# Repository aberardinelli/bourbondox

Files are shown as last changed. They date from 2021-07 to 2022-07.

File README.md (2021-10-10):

# bourbondox

`pcb/rev1` folder contains the KiCAD pcb files for v0.1 (received 2021-07-02)

`pcb/rev2` folder contains the KiCAD pcb files for v0.2 (received 2021-07-06)

`pcb/rev3` folder contains the KiCAD pcb files for v0.3 (received 2021-07-19)

`pcb/rev4` folder contains the KiCAD pcb files for v0.4 (received 2021-07-29)

`pcb/rev5` folder contains the KiCAD pcb files for v1.0 (received 2021-08-13)

`firmware` folder contains the qmk firmware files

`case/v1` folder contains the FreeCAD and dxf files for a stacked acrylic case that aligns with the v1.0 pcb (finished 2021-09-10)

There is also a json file (`keyboard-layout_rev1.0.json`) which could be used on keyboard-layout-editor.com

## Changelog and documentation of issues

### v0.1

* Only had one side printed. Diodes were mistakenly put on the front of the PCB in my schematic when they should be on the back.
* Soldered on reset button, promicro controller, and diodes.
* Tested each switch with tweezers. 
* All switches in columns 0, 1, 2, 3, and 4 worked as expected.
* All switches in columns 5 and 6 failed to register. Reset button failed to work.

### v0.2

* Had both sides printed this time. Completely redid the routing from scratch because I wasn't happy with the first version. Did all this and ordered the v0.2 prototypes before I had even received and tested v0.1.
* Soldered reset buttons, TRRS jacks, OLED screens, promicro controllers, diodes, and switches on both halves. Soldered resistors on right side only.
* Reset buttons still didn't work.  But... On each side, when plugged in alone (not connected to other half): All switches worked as expected. Both OLED screens worked as expected.
* When the sides are connected via TRRS cable, switches and OLED screens stopped working. This led me to believe there was a problem with the routing with the TRRS jacks. I ruled out a problem with the cable since I tried two different TRRS cables, both of which worked fine with two other split keyboards.
* Stagger on left hand felt extremely comfortable but right hand was unnatural.

### v0.3

* Changed the footprints on the PCB for the TRRS jacks and reset switches. Rerouted those components on the schematic.
* Reduced the stagger by a small bit on the left side. Reduced the stagger by a lot on the right side.
* Reset buttons work now, on both halves. 
* When it comes to testing the TRRS connection, there are multiple outcomes depending on configuration:
    * If right half has Elite-C and it is connected via USB-C cable to the computer, no switches register and OLEDs are blank.
    * If left half has ProMicro and it is connected via micro USB cable to the computer, no switches register, but the OLEDs each show the same garbled output (first few letters are clear and correct but the rest is nonsense).
    * If NOT connected via TRRS, but each half is connected via its respective USB cable directly to the computer, then OLED screens work as expected and all switches register as expected with tweezers.
* Stagger on left hand seems perfect; right hand might still need adjustments on pinky but seems perfect now for middle and ring fingers. 

### v0.4

* Changed the split communication to serial to allow OLED screens to use i2c. This required changing the routing and footprints in the schematics for the TRRS jacks.
* Very minor adjustments made to spacing of holes for OLED covers.
* Thumb cluster on right side was not great for my use case; rotated the keys on that side. 
* Increased the spacebar size on left side to 2u for more likely compatibility with keycap kits.

## v1.0 photos

*Initial build of v1.0 with cheap tenting provided by acrylic photo frames*
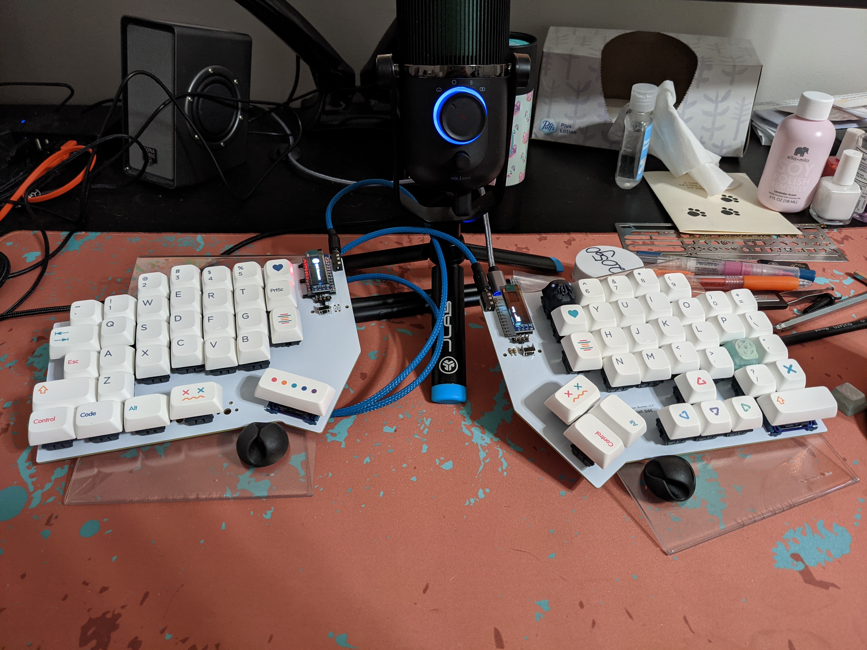
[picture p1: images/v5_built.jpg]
Initial v1.0 build


*v1.0 with better tenting provided by magnetic cell phone holders*
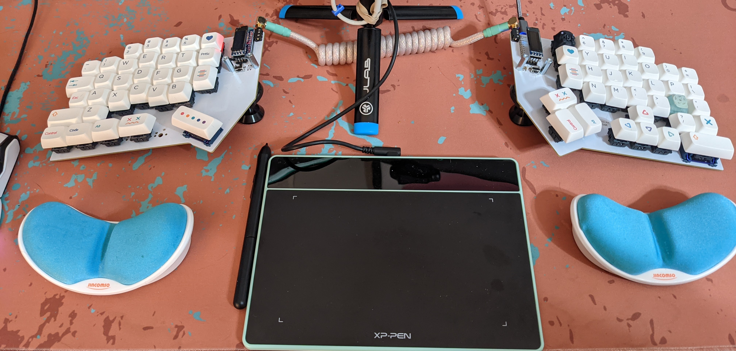
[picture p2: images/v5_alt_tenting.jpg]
v1.0 build with better tenting


## v0.4 photo

*First fully functional build!*
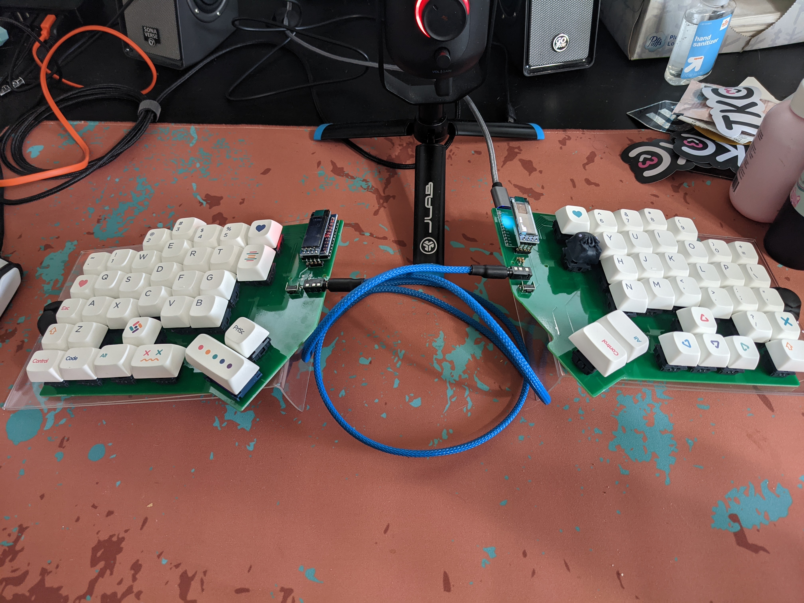
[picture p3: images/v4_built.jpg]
Initial v0.4 build


## v0.3 photos

*Not plugged in*
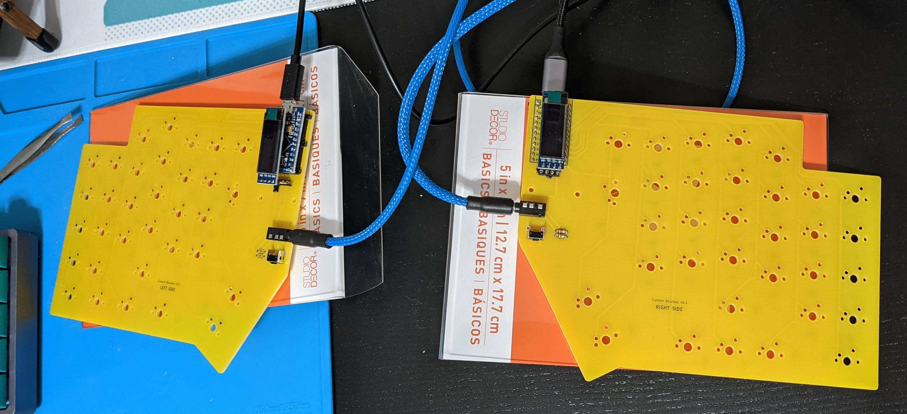
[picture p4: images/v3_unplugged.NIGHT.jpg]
Not plugged in


*Halves are NOT connected, each half is connected to computer via its own cable. OLEDs, switches, and reset buttons work as expected*
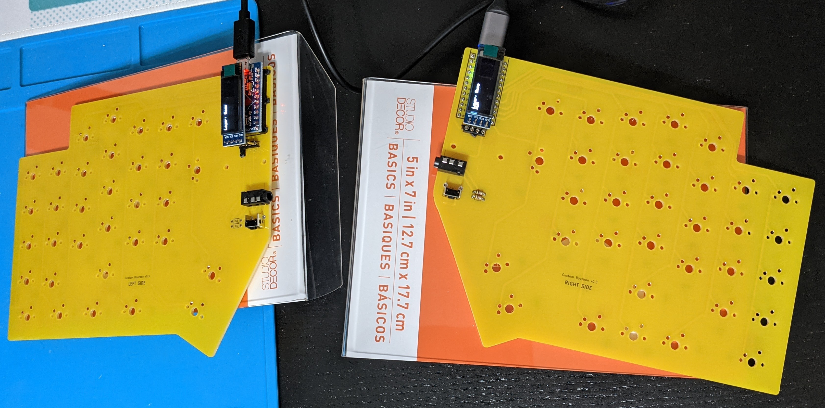
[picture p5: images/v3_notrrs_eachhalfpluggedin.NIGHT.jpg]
Right side plugged in via USB-C


*TRRS connecting the halves, connected to computer via USB-C cable plugged into Elite-C controller on right half of keyboard (controller power buttons light up, but no OLEDs and no switches register)*
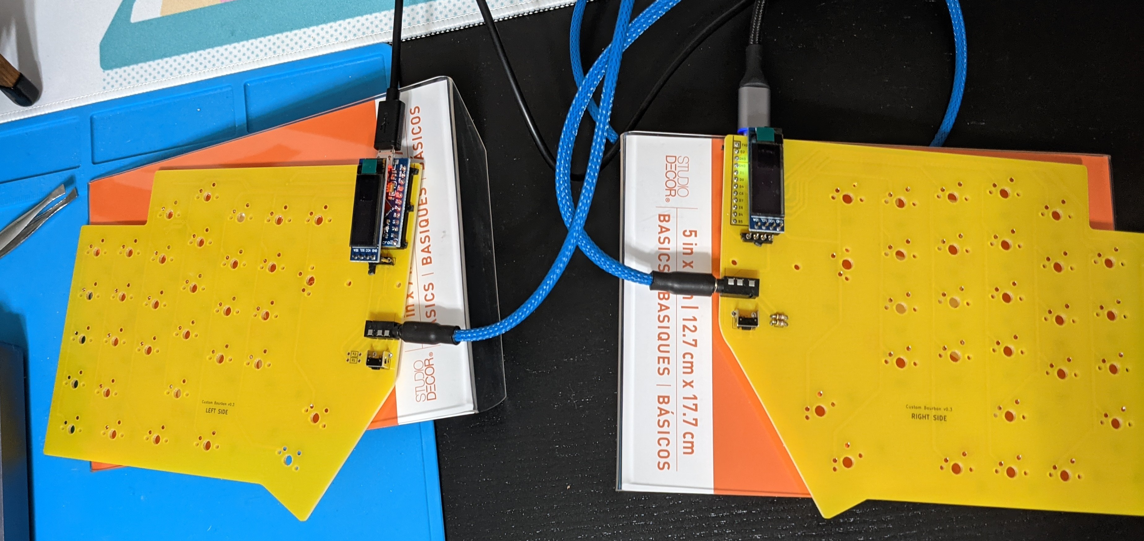
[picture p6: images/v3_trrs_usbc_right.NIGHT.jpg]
Right side plugged in via USB-C


*TRRS connecting the halves, connected to computer via micro USB cable plugged into ProMicro controller on left half of keyboard (controller power buttons light up, but no switches register; OLEDs light up but output is garbled)*
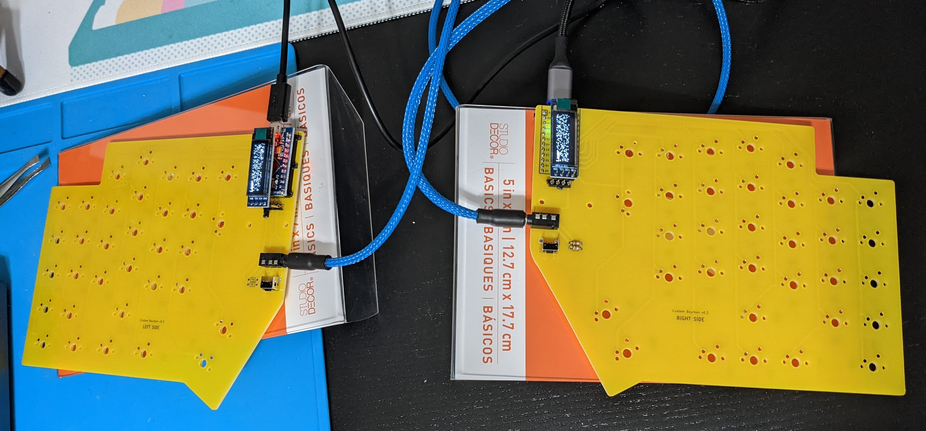
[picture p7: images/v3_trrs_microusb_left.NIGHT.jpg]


## v0.2 photo

*Everything's soldered, but it's not plugged in*
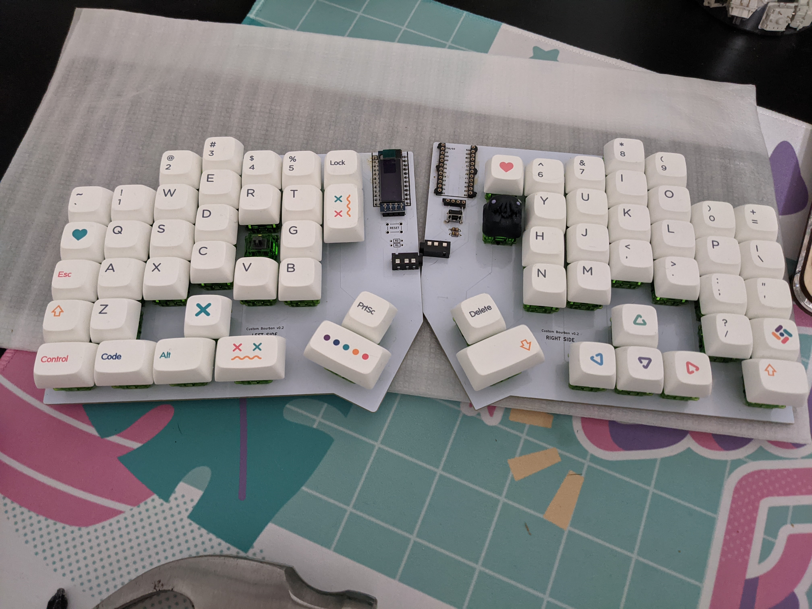
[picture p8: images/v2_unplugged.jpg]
Not plugged in


## v0.1 photos

*No soldering done yet, just placing switches and keycaps to verify fit.*
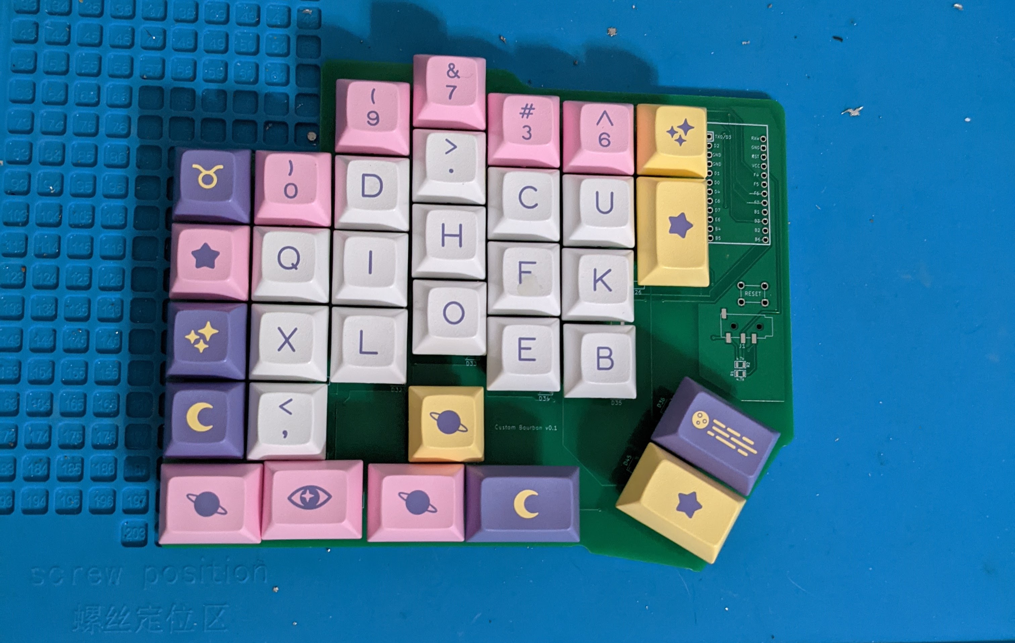
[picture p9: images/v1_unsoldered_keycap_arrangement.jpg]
No soldering done yet


*Soldered diodes, promicro, and reset button to the front. Yes, I know the diodes are supposed to be on the back of the PCB. This is fixed for v0.2.*
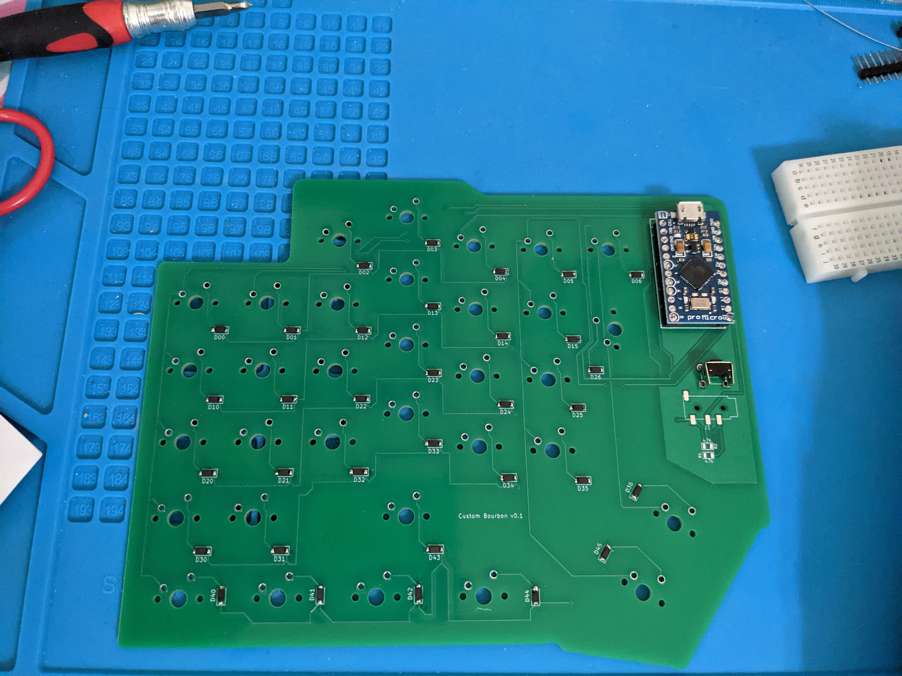
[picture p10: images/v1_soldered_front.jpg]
soldered components on front


*View of the soldering for the promicro on the back of the PCB.*
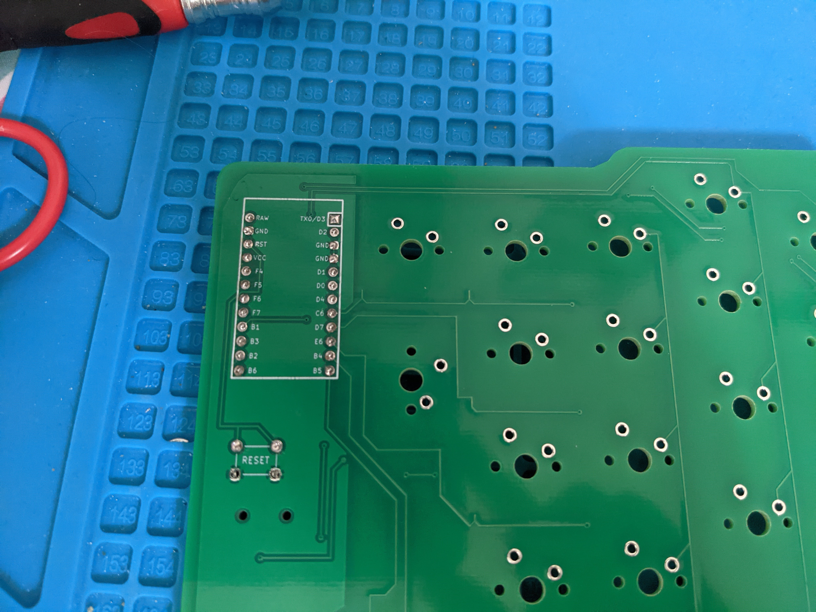
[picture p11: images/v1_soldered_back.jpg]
soldered components on back


*Promicro is flashed and soldered. Ready for testing!*
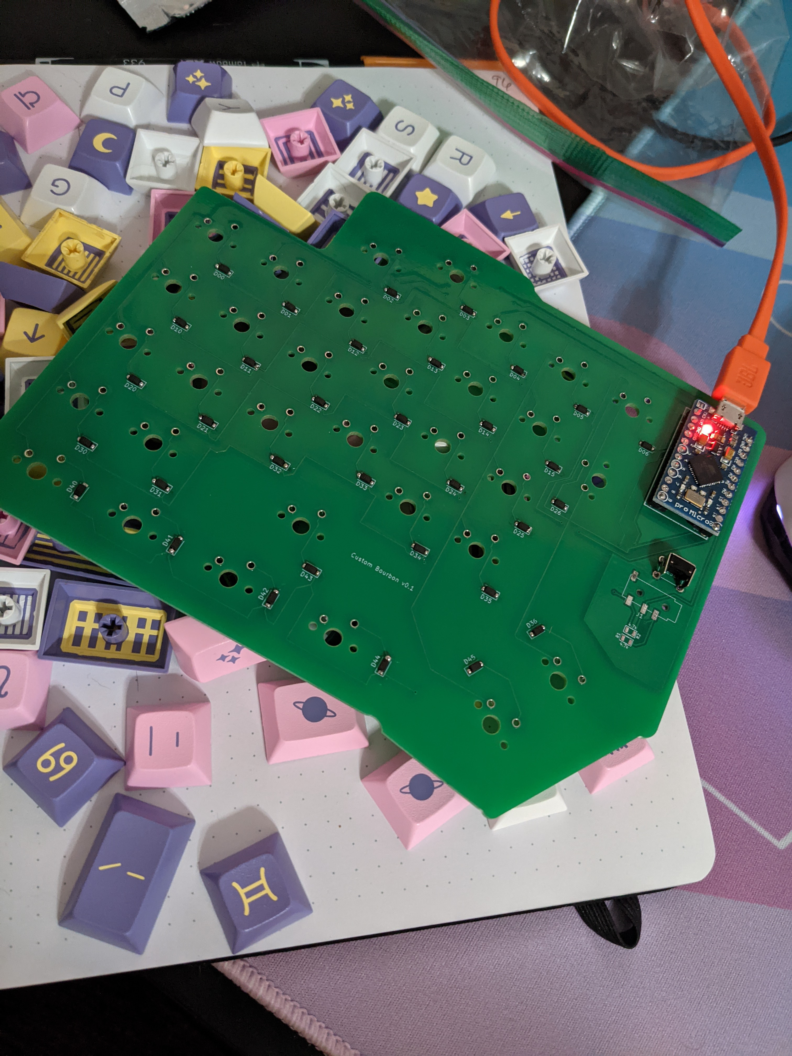
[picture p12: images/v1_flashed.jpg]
Ready for testing


# Acknowledgements

Thank you to ai03 and masterzen for your extensive keyboard pcb design tutorials posted online as resources for the community.

Thank you to the designers of the redox, lily58, and corne-cherry for sharing your work as open source. These were inspirational and helpful resources during my design of this keyboard.

Special thanks to the Keycraft Collective discord community, especially users astra and matthewdias, for their encouragement, feedback, input, and troubleshooting.

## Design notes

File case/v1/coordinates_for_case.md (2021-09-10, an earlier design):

# Left PCB

## Top to bottom measurements

Top layer: 9mm, needs holes for tadpoles 

Plate is ~1.5mm

Middle layers, in line with plate: 9.6mm gives 3mm clearance under pcb 

Acrylic comes in 1/4 inch thickness (>6.3mm)

## Outside points, from top left, clockwise, for all layers

* -76.70 49.70 arc up
* -68.78 55.47 horizontal
* -33.79 55.47 arc up 
* -27.48 61.03 vertical
* -27.48 76.01 arc up 
* -25.93 77.70 horizontal 
* 122.26 77.70 arc down
* 125.67 74.43 vertical
* 125.67 3.61 arc down 
* 123.49 -8.78 60deg from horizontal
* 88.61 -69.19 arc down 
* 80.20 -72.37 30deg from horizontal 
* 59.21 -60.25 arc up 
* 54.41 -58.95 horizontal 
* -68.66 -58.95 arc up 
* -76.7 -51.96 vertical 

## PCB inside points, from top left, clockwise 

Note: 8mm between pcb and outer edge of case

* -68.70 47.47
* -19.48 47.47
* -19.48 69.70
* 113.17 69.70
* 113.17 -10.65
* 82.21 -64.29
* 59.10 -50.95
* -68.70 -50.95

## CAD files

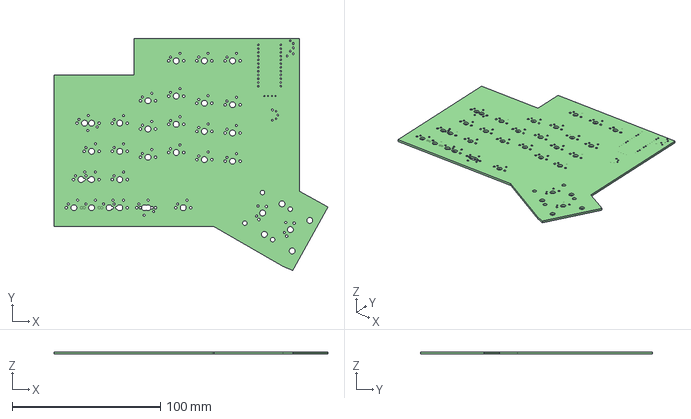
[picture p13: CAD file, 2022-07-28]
case/v3/left_case.FCStd
185.1 x 156.7 x 1.60 mm

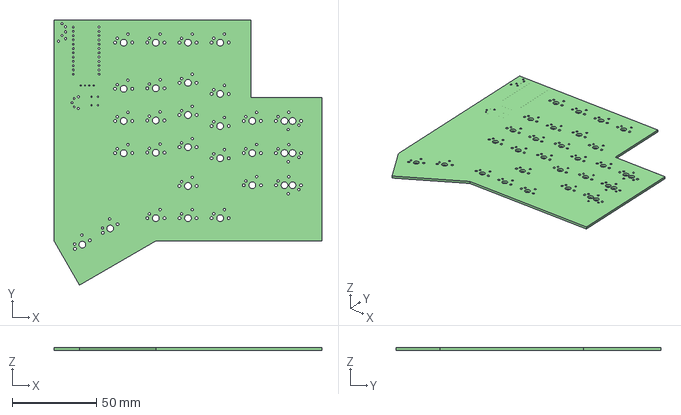
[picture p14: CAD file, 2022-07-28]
case/v3/right_case.FCStd
158.8 x 157.2 x 1.60 mm

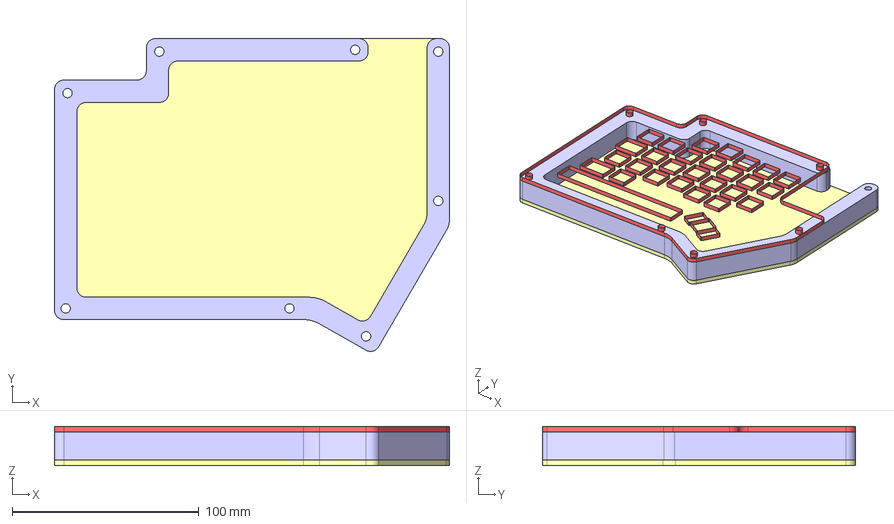
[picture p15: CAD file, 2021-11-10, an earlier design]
case/v1/left_case.FCStd
211.8 x 167.7 x 21.0 mm

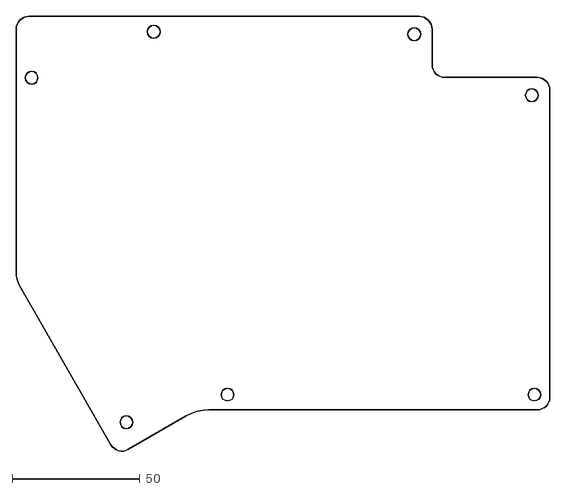
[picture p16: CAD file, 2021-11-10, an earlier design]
case/v2/right_bottom.dxf
208.6 x 170.1

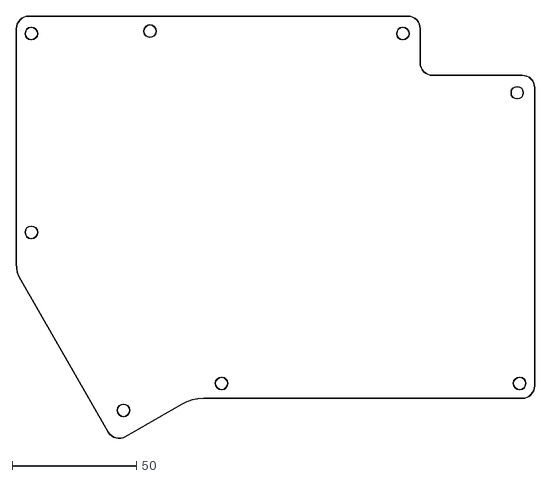
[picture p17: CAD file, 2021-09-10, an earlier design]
case/v1/right_bottom.dxf
208.6 x 170.1

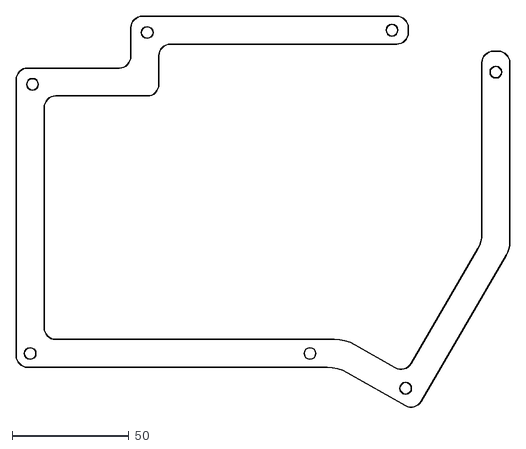
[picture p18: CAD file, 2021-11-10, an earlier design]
case/v2/left_outline.dxf
211.8 x 168.4

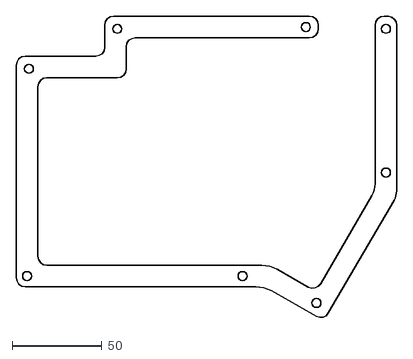
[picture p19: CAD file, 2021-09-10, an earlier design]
case/v1/left_outline.dxf
211.8 x 168.4

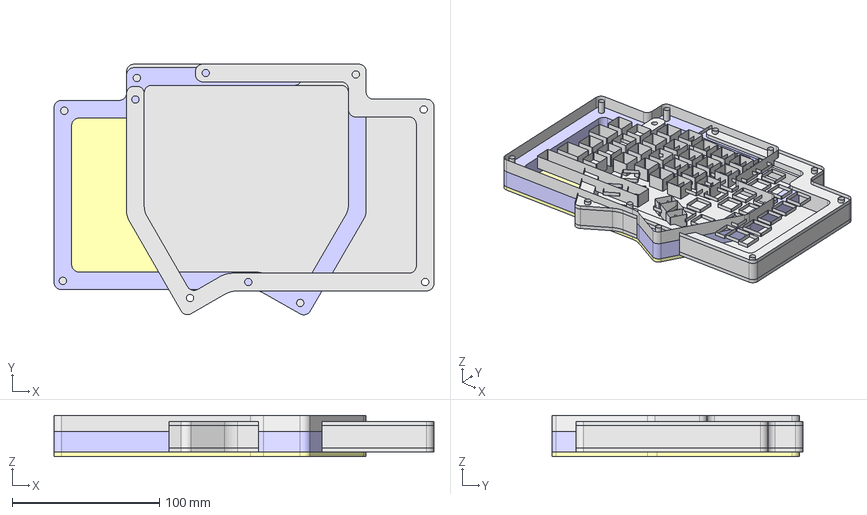
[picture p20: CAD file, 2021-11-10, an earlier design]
case/v2/left_case.FCStd
257.8 x 170.1 x 28.0 mm

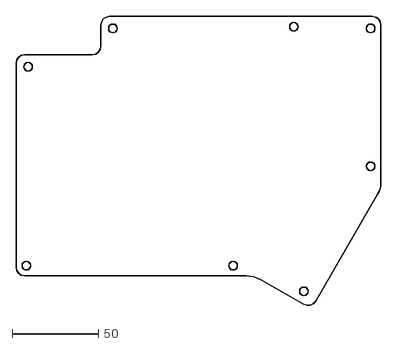
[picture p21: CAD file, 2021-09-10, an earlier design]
case/v1/left_bottom.dxf
211.8 x 168.4

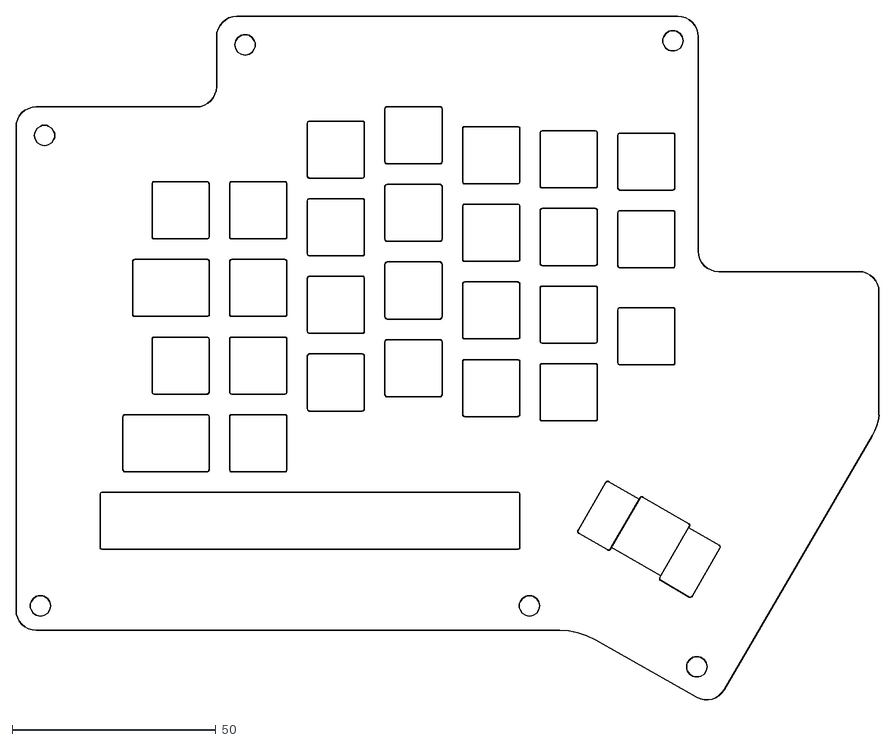
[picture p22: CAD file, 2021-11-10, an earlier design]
case/v2/left_plate.dxf
211.8 x 168.4

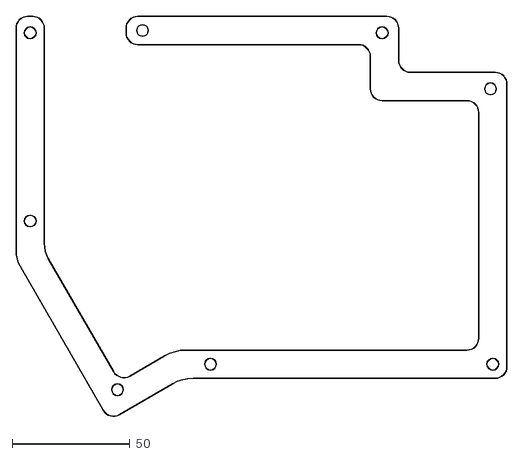
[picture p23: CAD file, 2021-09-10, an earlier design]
case/v1/right_outline.dxf
208.6 x 170.1

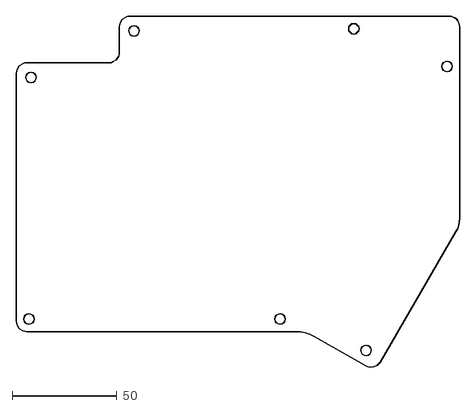
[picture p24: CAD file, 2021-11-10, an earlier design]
case/v2/left_bottom.dxf
211.8 x 168.4

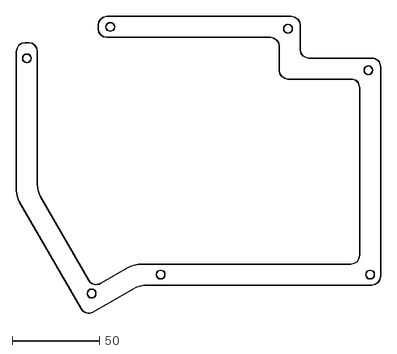
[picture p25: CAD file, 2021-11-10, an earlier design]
case/v2/right_outline.dxf
208.6 x 170.1

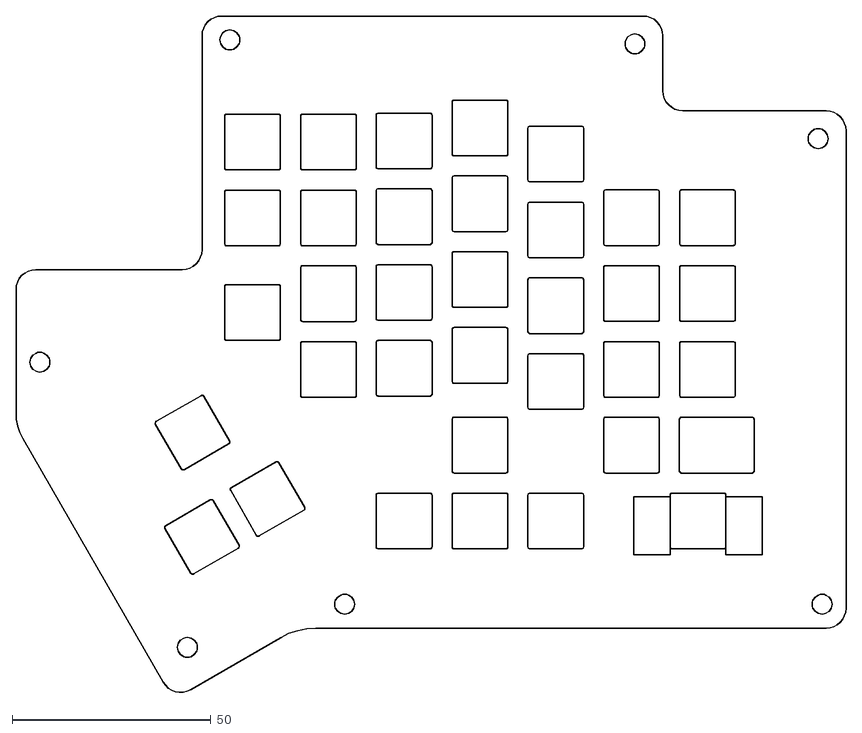
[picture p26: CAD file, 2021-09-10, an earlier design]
case/v1/right_plate.dxf
208.6 x 170.1

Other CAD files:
pcb/v2.0/bourbondox2_right.step
pcb/v2.0/bourbondox2_left.step
case/v1/right_case.FCStd
case/v2/right_plate.dxf
case/v1/left_plate.dxf

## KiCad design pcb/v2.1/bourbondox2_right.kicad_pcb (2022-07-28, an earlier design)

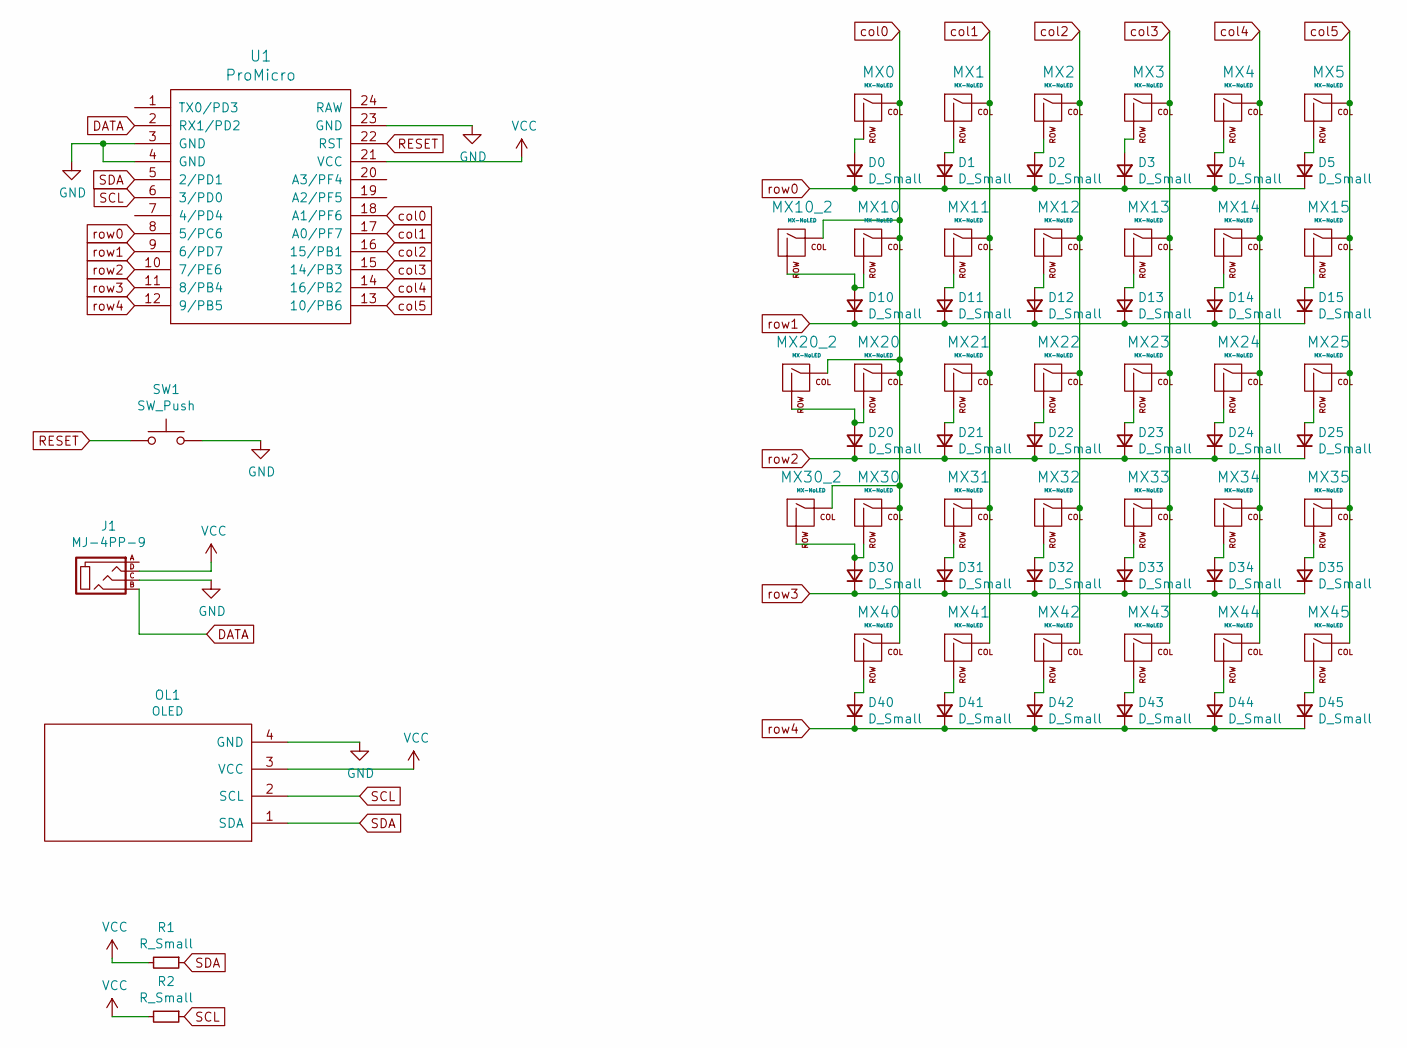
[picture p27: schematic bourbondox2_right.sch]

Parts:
D0, D1, D2, D3, D4, D5, D10, D11, D12, D13, D14, D15, D20, D21, D22, D23, D24, D25, D30, D31, D32, D33, D34, D35, D40, D41, D42, D43, D44, D45: D_Small; D_SOD-123
J1: MJ-4PP-9; MJ-4PP-9_1side
MX0, MX1, MX2, MX3, MX4, MX5, MX10, MX11, MX12, MX13, MX14, MX15, MX20, MX21, MX22, MX23, MX24, MX25, MX30, MX31, MX32, MX33, MX34, MX35, MX40, MX41, MX42, MX43: MX-NoLED; MXOnly-1U-NoLED
MX10_2, MX20_2, MX30_2: MX-NoLED; MXOnly-1.5U-NoLED
MX44, MX45: MX-NoLED; MXOnly-1.5U-Vertical-NoLED
OL1: OLED; OLED_4Pin
R1, R2: R_Small; RESISTOR_mini
SW1: SW_Push; SW_Tactile_SPST_Angled_MJTP1117
U1: ProMicro; ArduinoProMicro

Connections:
DATA: J1.B, U1.2 (RX1/PD2)
GND: J1.C, OL1.4 (GND), SW1.2, U1.3 (GND), U1.4 (GND), U1.23 (GND)
unnamed: D0.2 (A), MX0.2 (ROW)
unnamed: D1.2 (A), MX1.2 (ROW)
unnamed: D2.2 (A), MX2.2 (ROW)
unnamed: D3.2 (A), MX3.2 (ROW)
unnamed: D4.2 (A), MX4.2 (ROW)
unnamed: D5.2 (A), MX5.2 (ROW)
unnamed: D10.2 (A), MX10.2 (ROW), MX10_2.2 (ROW)
unnamed: D11.2 (A), MX11.2 (ROW)
unnamed: D12.2 (A), MX12.2 (ROW)
unnamed: D13.2 (A), MX13.2 (ROW)
unnamed: D14.2 (A), MX14.2 (ROW)
unnamed: D15.2 (A), MX15.2 (ROW)
unnamed: D20.2 (A), MX20.2 (ROW), MX20_2.2 (ROW)
unnamed: D21.2 (A), MX21.2 (ROW)
unnamed: D22.2 (A), MX22.2 (ROW)
unnamed: D23.2 (A), MX23.2 (ROW)
unnamed: D24.2 (A), MX24.2 (ROW)
unnamed: D25.2 (A), MX25.2 (ROW)
unnamed: D30.2 (A), MX30.2 (ROW), MX30_2.2 (ROW)
unnamed: D31.2 (A), MX31.2 (ROW)
unnamed: D32.2 (A), MX32.2 (ROW)
unnamed: D33.2 (A), MX33.2 (ROW)
unnamed: D34.2 (A), MX34.2 (ROW)
unnamed: D35.2 (A), MX35.2 (ROW)
unnamed: D40.2 (A), MX40.2 (ROW)
unnamed: D41.2 (A), MX41.2 (ROW)
unnamed: D42.2 (A), MX42.2 (ROW)
unnamed: D43.2 (A), MX43.2 (ROW)
unnamed: D44.2 (A), MX44.2 (ROW)
unnamed: D45.2 (A), MX45.2 (ROW)
RESET: SW1.1, U1.22 (RST)
SCL: OL1.2 (SCL), R2.1, U1.6 (3/PD0)
SDA: OL1.1 (SDA), R1.1, U1.5 (2/PD1)
VCC: J1.D, OL1.3 (VCC), R1.2, R2.2, U1.21 (VCC)
col0: MX0.1 (COL), MX10.1 (COL), MX10_2.1 (COL), MX20.1 (COL), MX20_2.1 (COL), MX30.1 (COL), MX30_2.1 (COL), MX40.1 (COL), U1.18 (A1/PF6)
col1: MX1.1 (COL), MX11.1 (COL), MX21.1 (COL), MX31.1 (COL), MX41.1 (COL), U1.17 (A0/PF7)
col2: MX2.1 (COL), MX12.1 (COL), MX22.1 (COL), MX32.1 (COL), MX42.1 (COL), U1.16 (15/PB1)
col3: MX3.1 (COL), MX13.1 (COL), MX23.1 (COL), MX33.1 (COL), MX43.1 (COL), U1.15 (14/PB3)
col4: MX4.1 (COL), MX14.1 (COL), MX24.1 (COL), MX34.1 (COL), MX44.1 (COL), U1.14 (16/PB2)
col5: MX5.1 (COL), MX15.1 (COL), MX25.1 (COL), MX35.1 (COL), MX45.1 (COL), U1.13 (10/PB6)
row0: D0.1 (K), D1.1 (K), D2.1 (K), D3.1 (K), D4.1 (K), D5.1 (K), U1.8 (5/PC6)
row1: D10.1 (K), D11.1 (K), D12.1 (K), D13.1 (K), D14.1 (K), D15.1 (K), U1.9 (6/PD7)
row2: D20.1 (K), D21.1 (K), D22.1 (K), D23.1 (K), D24.1 (K), D25.1 (K), U1.10 (7/PE6)
row3: D30.1 (K), D31.1 (K), D32.1 (K), D33.1 (K), D34.1 (K), D35.1 (K), U1.11 (8/PB4)
row4: D40.1 (K), D41.1 (K), D42.1 (K), D43.1 (K), D44.1 (K), D45.1 (K), U1.12 (9/PB5)

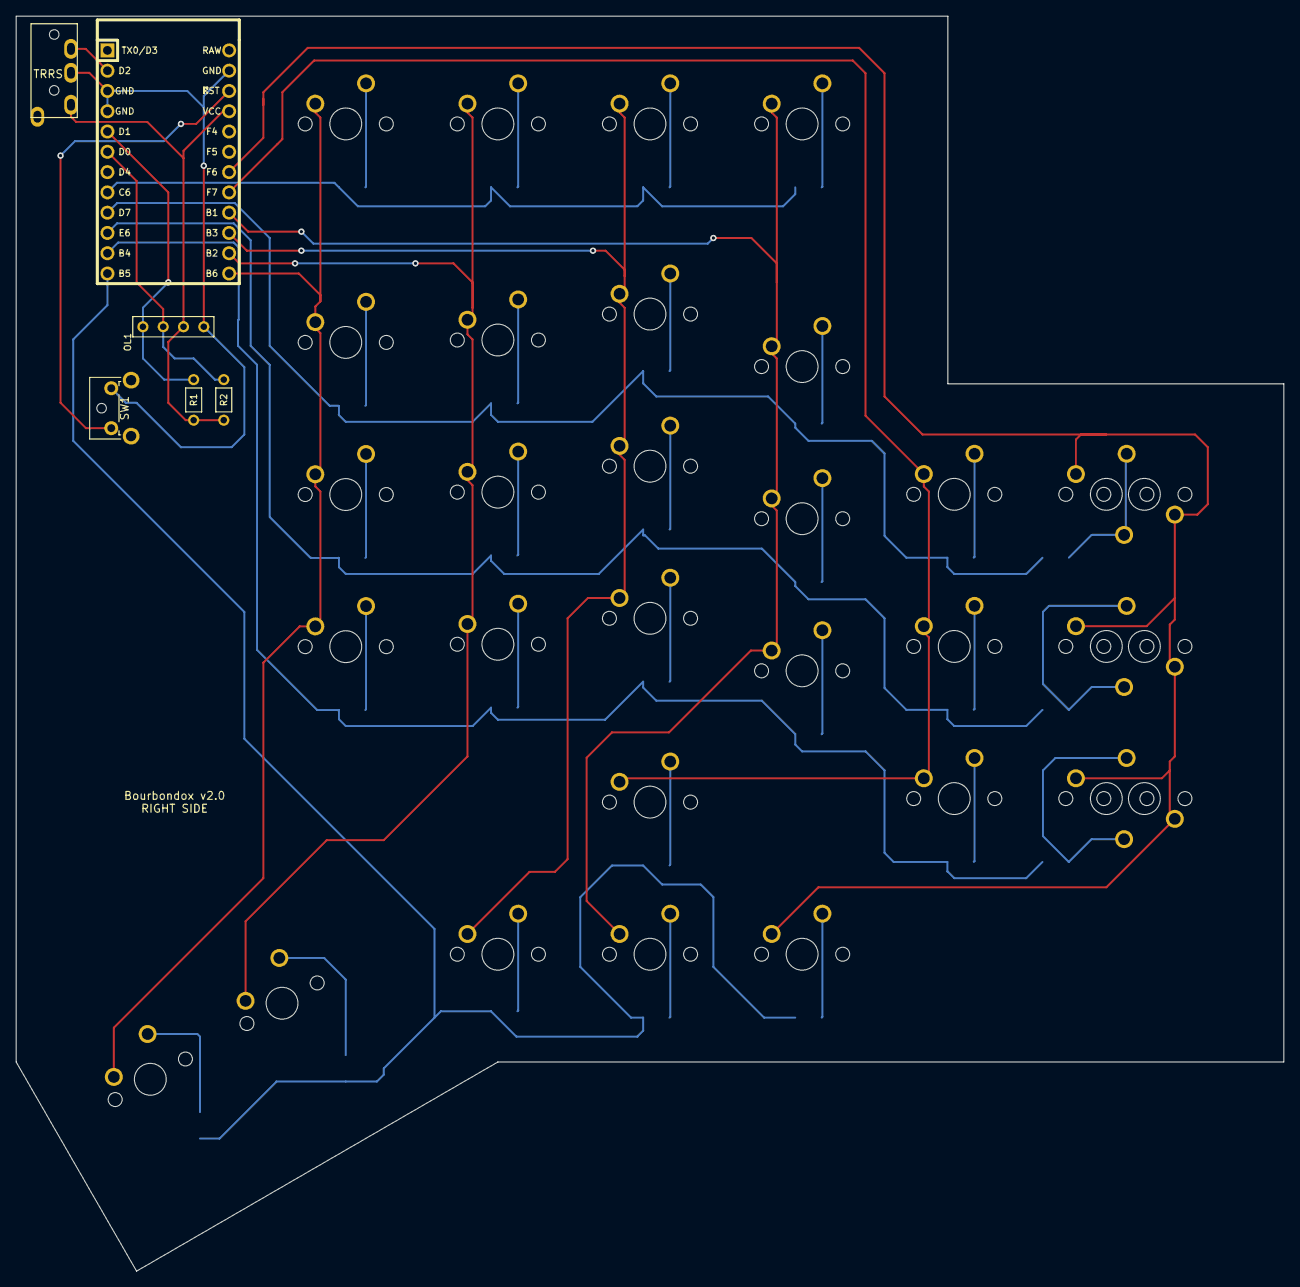
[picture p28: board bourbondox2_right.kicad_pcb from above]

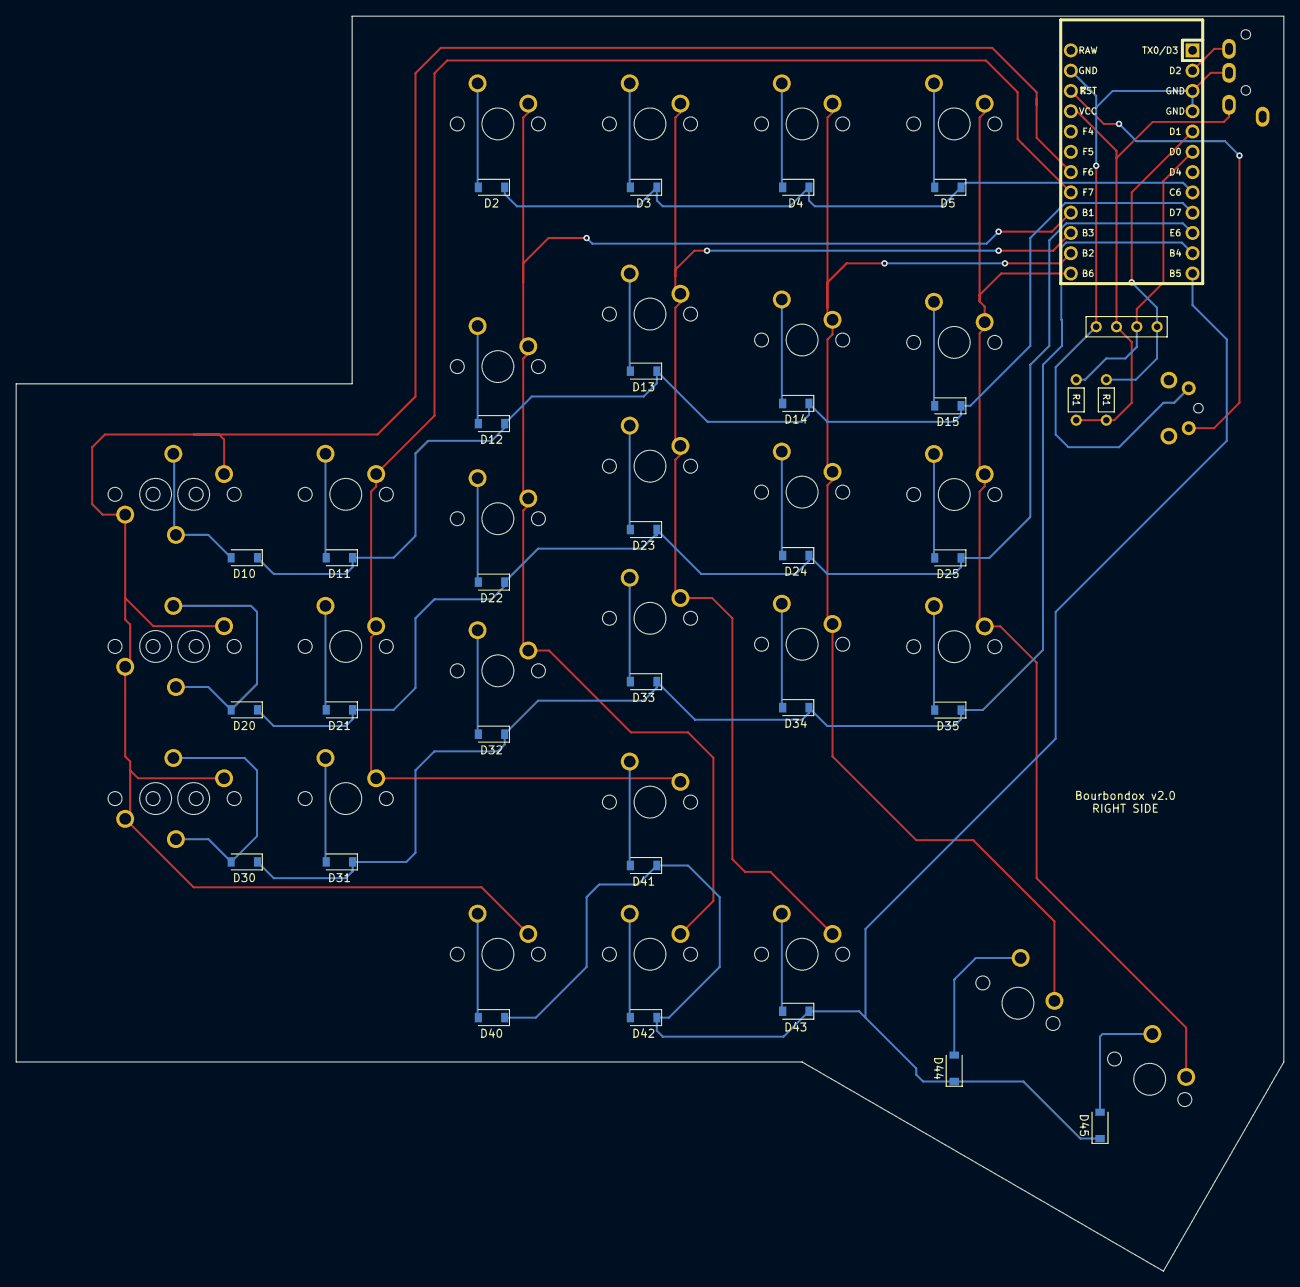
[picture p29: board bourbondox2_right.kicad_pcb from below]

Board: 2 copper layers, 158.8 x 157.2 mm, 65 parts (28 on the bottom side), 45 nets.

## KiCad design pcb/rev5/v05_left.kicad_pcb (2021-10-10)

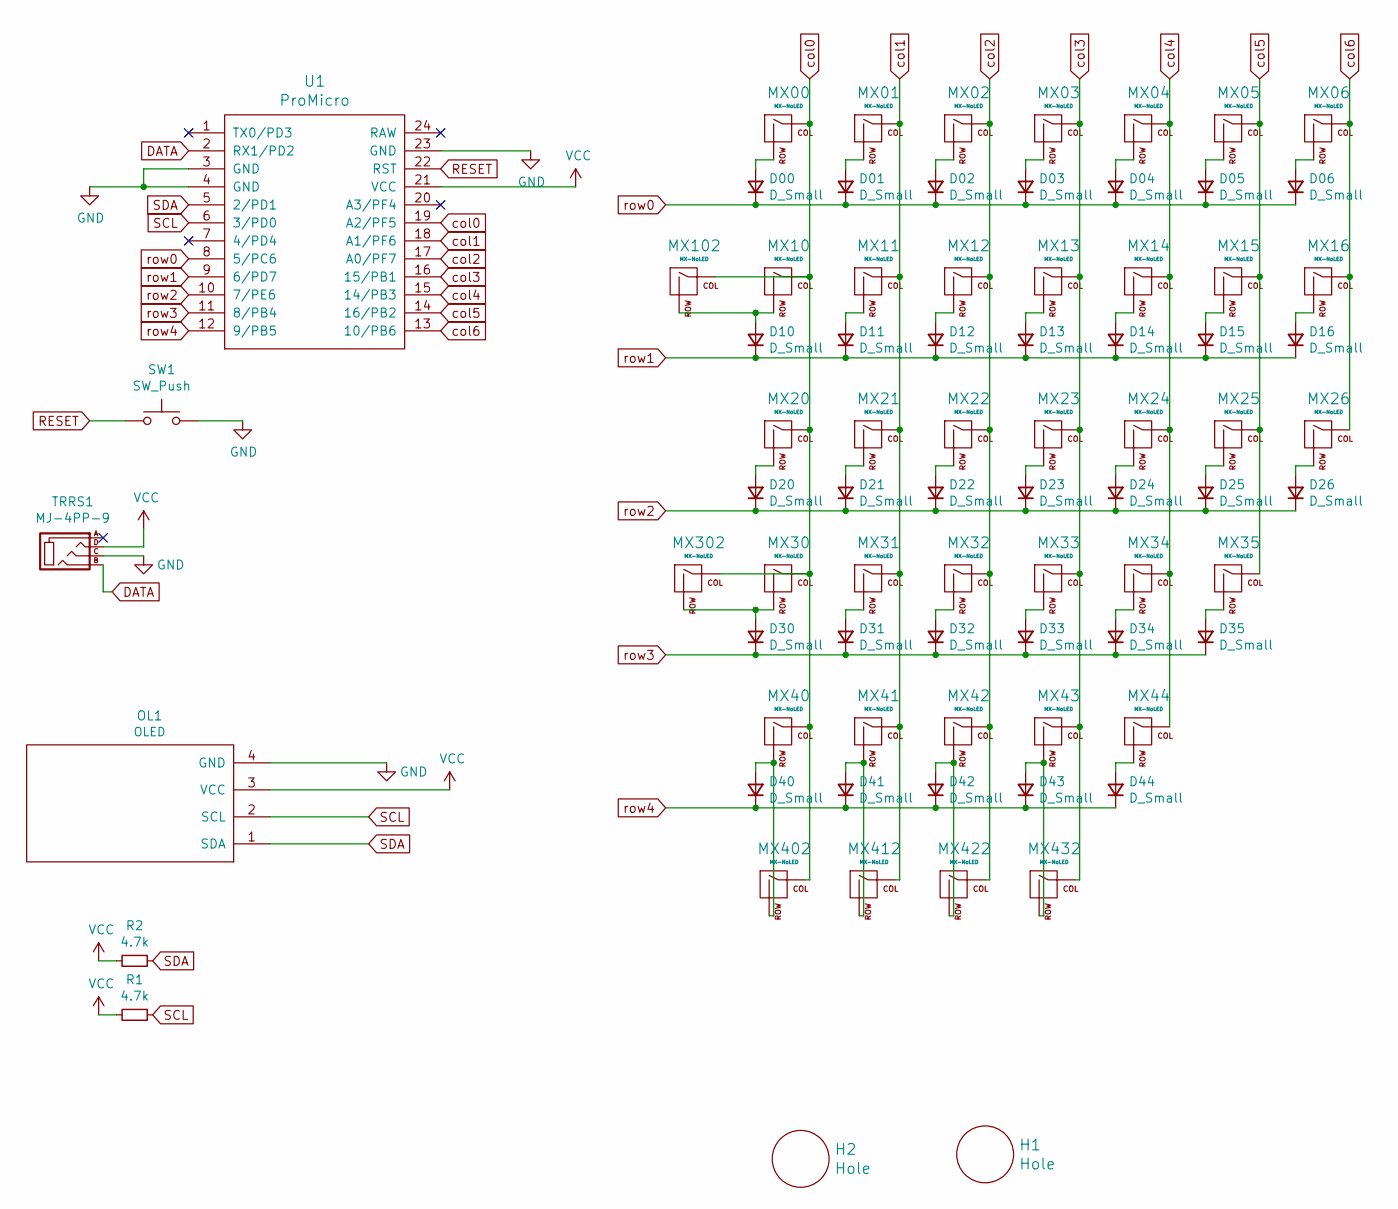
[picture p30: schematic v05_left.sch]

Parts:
D00, D01, D02, D03, D04, D05, D06, D10, D11, D12, D13, D14, D15, D16, D20, D21, D22, D23, D24, D25, D26, D30, D31, D32, D33, D34, D35, D40, D41, D42, D43, D44: D_Small; D_SOD-123
H1, H2: Hole; HOLE_M2
MX00, MX01, MX02, MX03, MX04, MX05, MX06, MX10, MX11, MX12, MX13, MX14, MX15, MX16, MX20, MX21, MX22, MX23, MX24, MX25, MX30, MX31, MX32, MX33, MX34, MX35: MX-NoLED; MXOnly-1U-NoLED
MX26, MX43, MX102, MX432: MX-NoLED; MXOnly-1.5U-NoLED
MX40, MX41, MX42, MX402, MX412, MX422: MX-NoLED; MXOnly-1.25U-NoLED
MX44: MX-NoLED; MXOnly-2U-NoLED
MX302: MX-NoLED; MXOnly-1.75U-NoLED
OL1: OLED; OLED_4Pin
R1, R2: 4.7k; RESISTOR_mini
SW1: SW_Push; SW_Tactile_SPST_Angled_MJTP1117
TRRS1: MJ-4PP-9; MJ-4PP-9_1side
U1: ProMicro; ArduinoProMicro

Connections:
DATA: TRRS1.B, U1.2 (RX1/PD2)
GND: OL1.4 (GND), SW1.2, TRRS1.C, U1.3 (GND), U1.4 (GND), U1.23 (GND)
unnamed: D00.2 (A), MX00.2 (ROW)
unnamed: D01.2 (A), MX01.2 (ROW)
unnamed: D02.2 (A), MX02.2 (ROW)
unnamed: D03.2 (A), MX03.2 (ROW)
unnamed: D04.2 (A), MX04.2 (ROW)
unnamed: D05.2 (A), MX05.2 (ROW)
unnamed: D06.2 (A), MX06.2 (ROW)
unnamed: D10.2 (A), MX10.2 (ROW), MX102.2 (ROW)
unnamed: D11.2 (A), MX11.2 (ROW)
unnamed: D12.2 (A), MX12.2 (ROW)
unnamed: D13.2 (A), MX13.2 (ROW)
unnamed: D14.2 (A), MX14.2 (ROW)
unnamed: D15.2 (A), MX15.2 (ROW)
unnamed: D16.2 (A), MX16.2 (ROW)
unnamed: D20.2 (A), MX20.2 (ROW)
unnamed: D21.2 (A), MX21.2 (ROW)
unnamed: D22.2 (A), MX22.2 (ROW)
unnamed: D23.2 (A), MX23.2 (ROW)
unnamed: D24.2 (A), MX24.2 (ROW)
unnamed: D25.2 (A), MX25.2 (ROW)
unnamed: D26.2 (A), MX26.2 (ROW)
unnamed: D30.2 (A), MX30.2 (ROW), MX302.2 (ROW)
unnamed: D31.2 (A), MX31.2 (ROW)
unnamed: D32.2 (A), MX32.2 (ROW)
unnamed: D33.2 (A), MX33.2 (ROW)
unnamed: D34.2 (A), MX34.2 (ROW)
unnamed: D35.2 (A), MX35.2 (ROW)
unnamed: D40.2 (A), MX40.2 (ROW), MX402.2 (ROW)
unnamed: D41.2 (A), MX41.2 (ROW), MX412.2 (ROW)
unnamed: D42.2 (A), MX42.2 (ROW), MX422.2 (ROW)
unnamed: D43.2 (A), MX43.2 (ROW), MX432.2 (ROW)
unnamed: D44.2 (A), MX44.2 (ROW)
RESET: SW1.1, U1.22 (RST)
SCL: OL1.2 (SCL), R1.1, U1.6 (3/PD0)
SDA: OL1.1 (SDA), R2.1, U1.5 (2/PD1)
VCC: OL1.3 (VCC), R1.2, R2.2, TRRS1.D, U1.21 (VCC)
col0: MX00.1 (COL), MX10.1 (COL), MX20.1 (COL), MX30.1 (COL), MX40.1 (COL), MX102.1 (COL), MX302.1 (COL), MX402.1 (COL), U1.19 (A2/PF5)
col1: MX01.1 (COL), MX11.1 (COL), MX21.1 (COL), MX31.1 (COL), MX41.1 (COL), MX412.1 (COL), U1.18 (A1/PF6)
col2: MX02.1 (COL), MX12.1 (COL), MX22.1 (COL), MX32.1 (COL), MX42.1 (COL), MX422.1 (COL), U1.17 (A0/PF7)
col3: MX03.1 (COL), MX13.1 (COL), MX23.1 (COL), MX33.1 (COL), MX43.1 (COL), MX432.1 (COL), U1.16 (15/PB1)
col4: MX04.1 (COL), MX14.1 (COL), MX24.1 (COL), MX34.1 (COL), MX44.1 (COL), U1.15 (14/PB3)
col5: MX05.1 (COL), MX15.1 (COL), MX25.1 (COL), MX35.1 (COL), U1.14 (16/PB2)
col6: MX06.1 (COL), MX16.1 (COL), MX26.1 (COL), U1.13 (10/PB6)
row0: D00.1 (K), D01.1 (K), D02.1 (K), D03.1 (K), D04.1 (K), D05.1 (K), D06.1 (K), U1.8 (5/PC6)
row1: D10.1 (K), D11.1 (K), D12.1 (K), D13.1 (K), D14.1 (K), D15.1 (K), D16.1 (K), U1.9 (6/PD7)
row2: D20.1 (K), D21.1 (K), D22.1 (K), D23.1 (K), D24.1 (K), D25.1 (K), D26.1 (K), U1.10 (7/PE6)
row3: D30.1 (K), D31.1 (K), D32.1 (K), D33.1 (K), D34.1 (K), D35.1 (K), U1.11 (8/PB4)
row4: D40.1 (K), D41.1 (K), D42.1 (K), D43.1 (K), D44.1 (K), U1.12 (9/PB5)

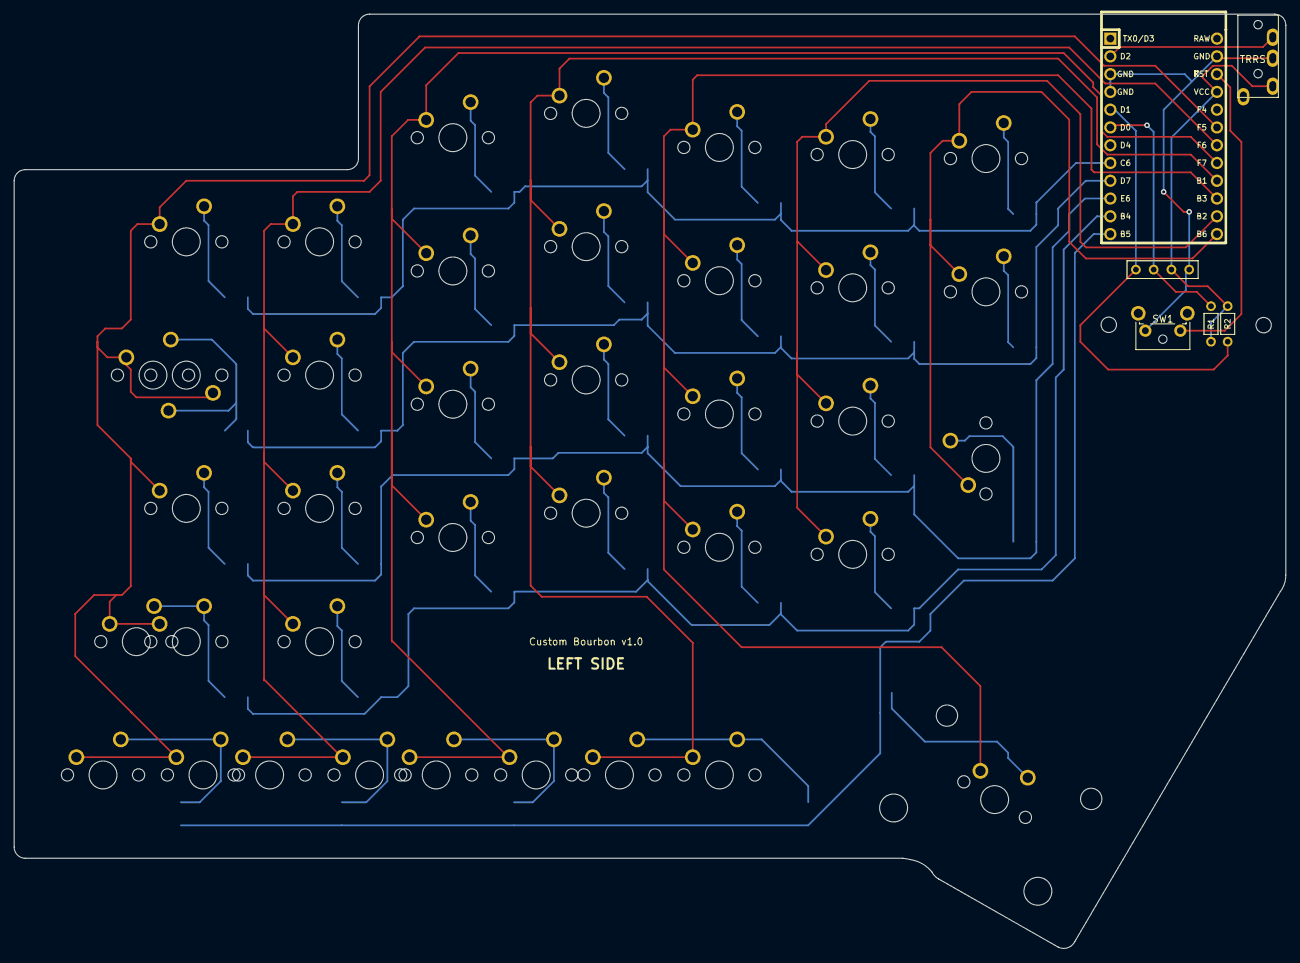
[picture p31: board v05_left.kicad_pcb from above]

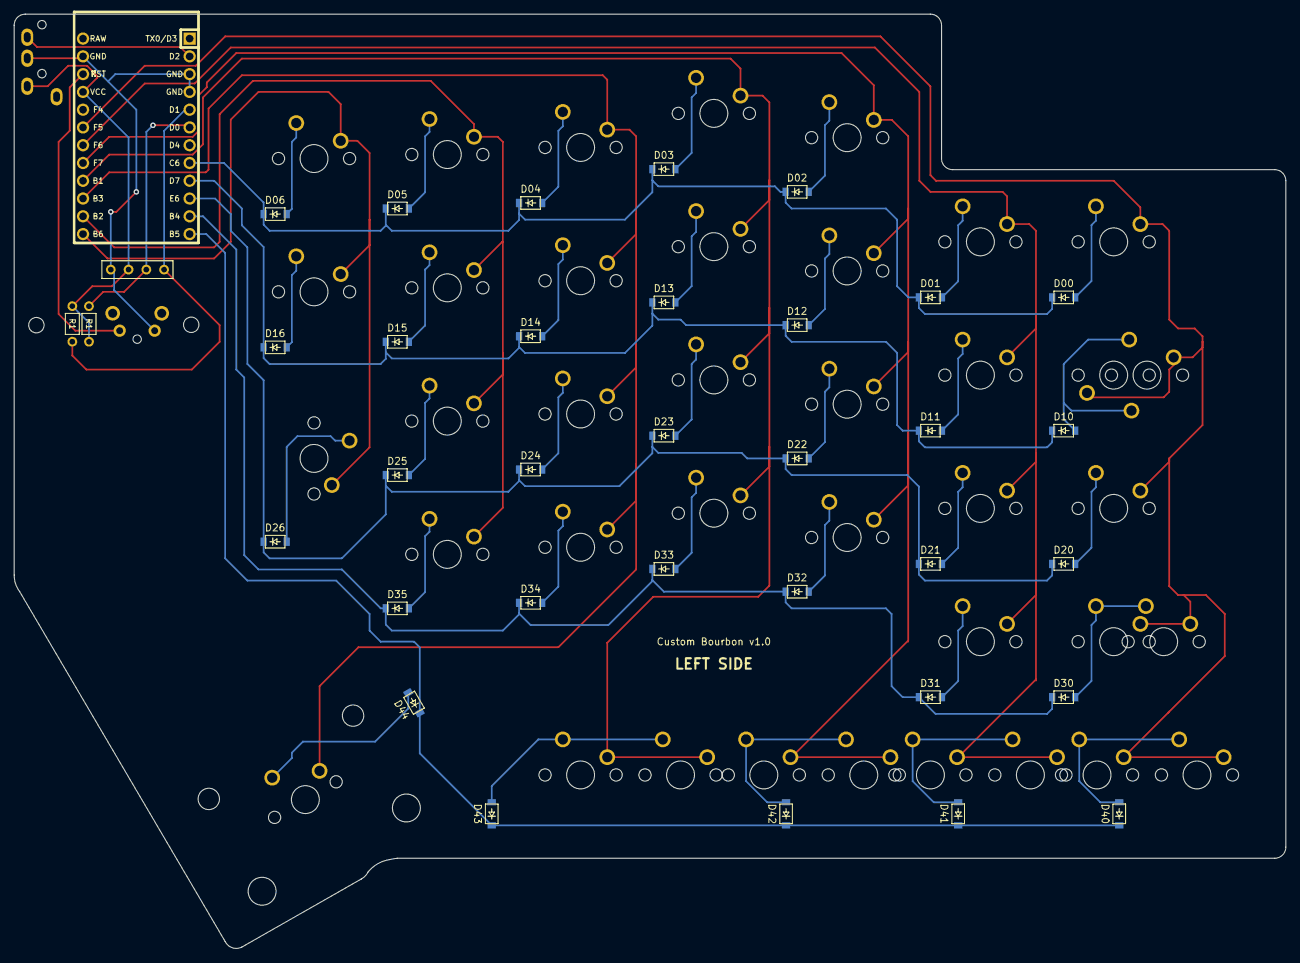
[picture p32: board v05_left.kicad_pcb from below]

Board: 2 copper layers, 181.8 x 133.5 mm, 78 parts (32 on the bottom side), 50 nets.

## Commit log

2021-07-05 Uploaded QMK firmware files and v0.1 pcb files
    [attempt2-B_Cu.gbl, attempt2-B_Mask.gbs, attempt2-B_SilkS.gbo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]
2021-07-05 Renamed folders for clarity; added photos
    [attempt2-B_Cu.gbl, attempt2-B_Mask.gbs, attempt2-B_SilkS.gbo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]
2021-07-11 Started v0.3; left side modifications done: slightly decreased pinky stagger, added holes for OLED cover, rerouted TRRS and reset button
    [v02_left.kicad_pcb, v02_left.sch, v02_right.kicad_pcb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]
2021-07-11 Started edits for right side for v0.3; added holes for OLED cover, fixed TRRS and reset switch footprints
    [v02_right.kicad_pcb, v02_right.sch]
2021-07-11 Fixed routing for right side for v0.3
    [v02_left.kicad_pcb, v02_right.kicad_pcb]
2021-07-11 Finalized routing for right side of v0.3
    [v02_right.kicad_pcb]
2021-07-11 Generated gerber files for v0.3
    [v02_left-B_Cu.gbl, v02_left-B_Mask.gbs, v02_left-B_SilkS.gbo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]
2021-07-25 Created folder for v0.4; modified TRRS jack in schematic to serial communication
    [v04_left.kicad_pcb, v04_left.sch, v04_right.kicad_pcb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]
2021-07-25 Fixed footprint for TRRS jack in right side and rerouted.
    [v04_right.kicad_pcb]
2021-07-25 Fixed footprint for TRRS jack in left side and rerouted.
    [v04_left.kicad_pcb]
2021-07-25 Updated silks for v0.4
    [v04_left.kicad_pcb, v04_right.kicad_pcb]
2021-07-25 Moved the OLED cover holes slightly for better fit
    [v04_left.kicad_pcb, v04_right.kicad_pcb]
2021-07-25 Repositioned both thumb clusters; fixed positioning of z key on left side
    [v04_left.kicad_pcb, v04_left.sch, v04_right.kicad_pcb]
2021-08-01 Started final(?) revision, v1.0
    [v04_left-B_Cu.gbl, v04_left-B_Mask.gbs, v04_left-B_SilkS.gbo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]
2021-08-01 Modified right side: moved misc components under OLED cover, added keys in column 6
    [v05_right.kicad_pcb]
2021-09-10 Updated README, added latest firmware, case, and pcb files
    [left_bottom.dxf, left_case.FCStd, left_outline.dxf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]
2021-10-10 Reorganized folder structure
    [attempt2-B_Cu.gbl, attempt2-B_Mask.gbs, attempt2-B_SilkS.gbo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]
2021-11-10 Generated files for v2 case printing
    [left_bottom.dxf, left_case.FCStd, left_outline.dxf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]
2022-04-13 v2.0 of pcb added
    [bourbondox2_left-B_Cu.gbl, bourbondox2_left-B_Mask.gbs, bourbondox2_left-B_SilkS.gbo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]
2022-07-28 Modifications to PCB made on laptop
    [bourbondox2_left-B_Cu.gbl, bourbondox2_left-B_Mask.gbs, bourbondox2_left-B_SilkS.gbo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]
2024-01-09 Cleaning files off Asus ZenBook
    [bourbondox2_left.kicad_pcb, bourbondox2_left.step, bourbondox2_right.kicad_pcb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]
